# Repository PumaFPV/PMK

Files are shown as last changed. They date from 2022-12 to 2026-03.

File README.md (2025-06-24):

# Puma Mechanical Keyboard
PMK - a full wireless HID ecosystem for split keyboards and other fun devices

The goal is to make a suit of wireless devices such as "smart keyboard" (combined mouse and keyboard), gamepad, LEDs, knobs, display, etc  
The first step is to make a wireless split keyboard, and then we will see later...

Currently, you can connect up to 8 (software limited) devices per dongle, each of them having up to 8 (software limited) layers. Layers only affect keyboards and LED.

## Dongle
The dongle is "master" ESP32S2/S3, appears as HID (keyboard, mouse and joystick) and as Mass Storage device Class with config files inside.
Maybe also store password manager later...

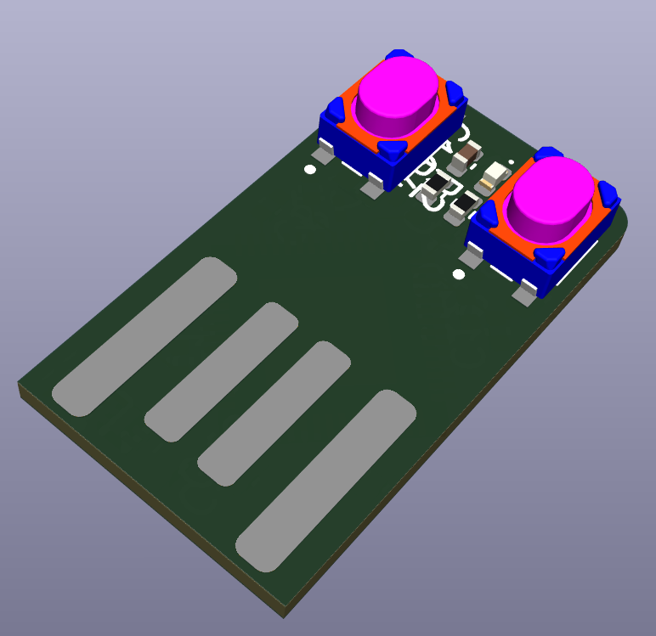
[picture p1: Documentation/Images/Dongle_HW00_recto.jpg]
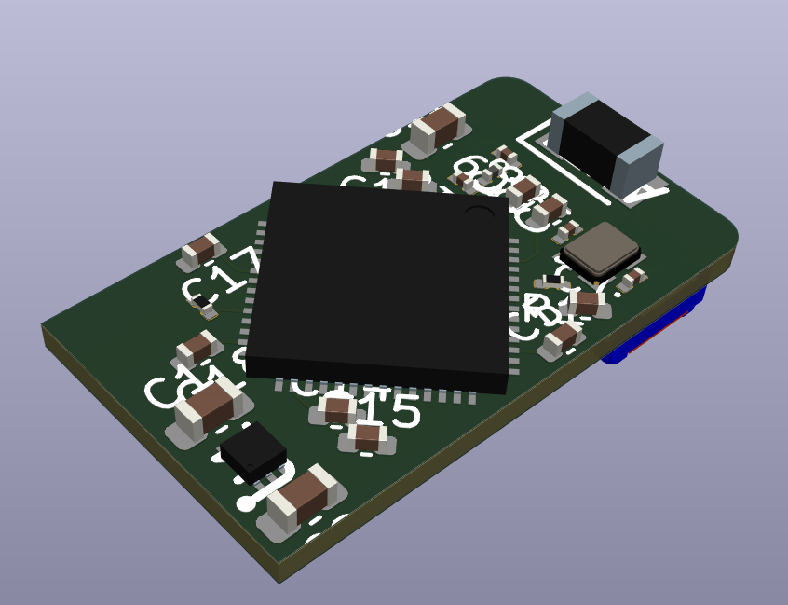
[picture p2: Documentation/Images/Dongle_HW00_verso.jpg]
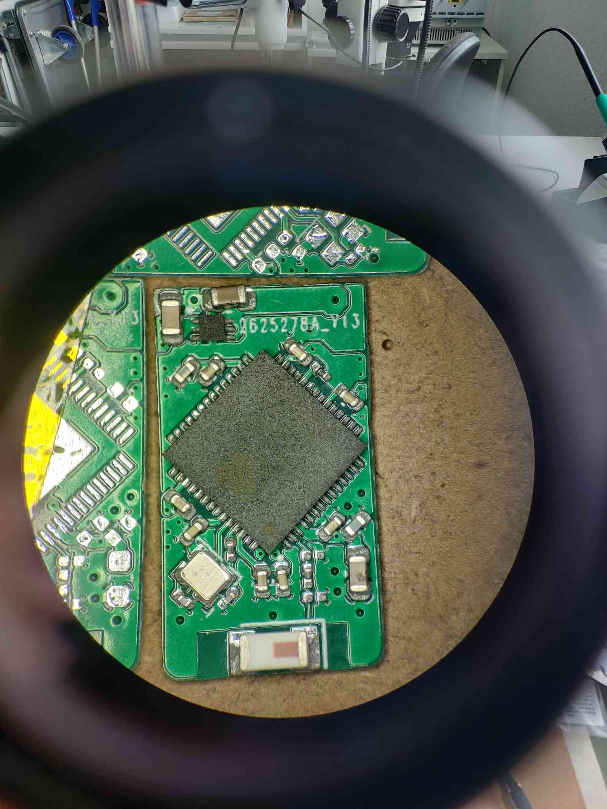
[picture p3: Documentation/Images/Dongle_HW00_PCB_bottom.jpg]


As the dongle is the master of PMK, it hosts the config files for each devices. Here is the expected file organisation:

		|--deviceName1  
		|  |- deviceName1.json  
		|  |--keyboard  
		|  |  |- kb-l1.json  
		|  |  |- kb-l2.json  
		|  |--led  
		|  |  |- led-l1.json  
		|  |  |- led-l2.json  
		|--deviceName2  
		|  |- deviceName2.json  
		|  |--keyboard  
		|  |  |- kb-l1.json  
		|  |  |- kb-l2.json  

Exemple file structure can be found [here](https://github.com/PumaFPV/PMK/tree/main/Software/PMK_dongle/data/leftKB) 

For more details about devices configurations / capabilities check the [Protocol](https://github.com/PumaFPV/PMK?tab=readme-ov-file#protocols) chapter.

### Keyboard config file - HID codes
Check out the [PMK HID keyboard keycodes.md](https://github.com/PumaFPV/PMK/blob/main/PMK%20HID%20keyboard%20keycodes.md) for more information on which code corresponds to which key.

## Devices
Can run on any espressif chip that can run ESP-NOW. (I will later add support for nRF52 chips for lower power consumption, but it will be incompatible with ESP32 hardware)
The plan is to run the simplest firmware on all devices and being able to configure them via their corresponding .json files on the master dongle. 
Each device should be configurable via UART (set device ID, set dongle MAC address, and read device MAC address). 
See sample [device code](https://github.com/PumaFPV/PMK/tree/main/Software/PMK_device) for example. (Needs an update)

### Keyboard
For example a keyboard would send pressed keys number "0x04, 0xA1", which the dongle then reads in the .json as coordinates for returning desired key "a,b", if special key is pressed (volume up, brighntess control...) then do the appropriate consummer control action.
Keys are read with 74HC165 shift registers so theoratically you could have A LOT of keys per keyboard. Current limitation is the max value of keyID which is 255, so there could be a maximum of 255 keys per keyboard (+8 layers...).
For more information about the hardawre, check the [hardware](https://github.com/PumaFPV/PMK/tree/main?tab=readme-ov-file#hardware) section.
A casing is being designed, it is 3D printable. As foam grid is put inside for better sound (I think it is better?). 
It support module on the thumb side ([Circle trackpad](https://www.cirque.com/glidepoint-circle-trackpads) and [3D mouse](https://hackaday.io/project/187172-os3m-mouse)). Both modules have been tested and work. See [Space mouse](https://github.com/PumaFPV/PMK/tree/main?tab=readme-ov-file#space-mouse) section for more info.

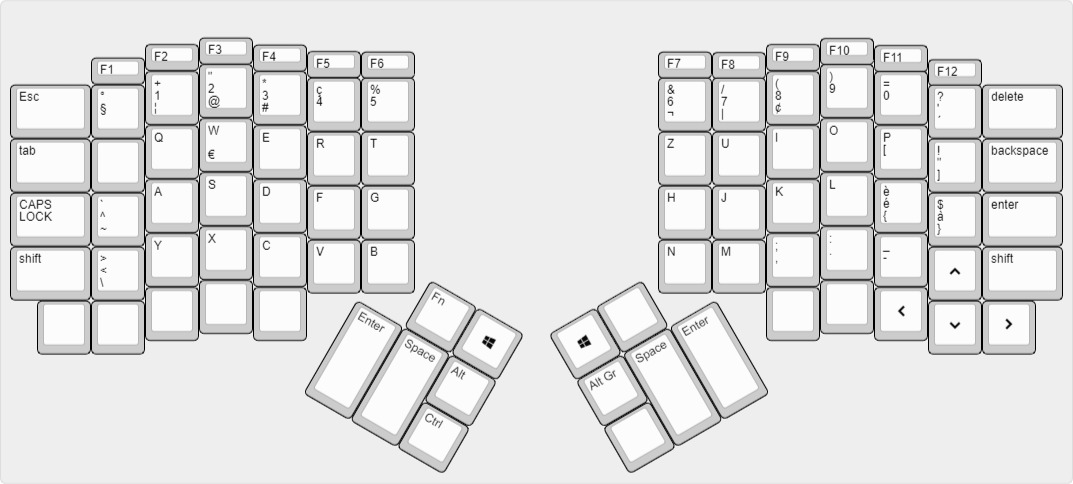
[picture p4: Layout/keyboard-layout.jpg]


### Mouse
Mouse can send x,y movement, wheel, pan scrolling and mouse buttons (left, middle, right, forward, backward). Each button is encoded as a bit in the "key" byte of the packet.
No configuration needed on the dongle appart from the DPI setting.
I plan on retro fitting a wired Logitech G300 with PMK so that it frees up a USB port + becomes wireless. It will be a great first POC. I also have a M330 laying around. It might also end up as a PMK mouse.

### Gamepad
Gamepad can send 2 analog joysticks, 2 analog triggers, dpad buttons, and 32 additionnal buttons. No additionnal configuration needed on the dongle.
I current upgraded an old thrustmaster sim set (FCS & WCS) from 1992 with PMK. They used to have an ADB port, but now both are fully wireless and appear as one gamepad on the computer. The update is a bit crude as it was first though as a POC for trying out the gamepad feature. But since it works fine, I kept it this way.

### LED
(For release 1.2.0)
Hopefully processing key press and led function on dongle and send data to device is fast enough, otherwise I will have to run led function on keyboard. (TODO)
Buildin keyboard functions: all kb, breath, swipe wave (single color or rainbow), key wave, single key... (TODO / Partially implemented...)
Uses the WS2812 kind of LED IC.

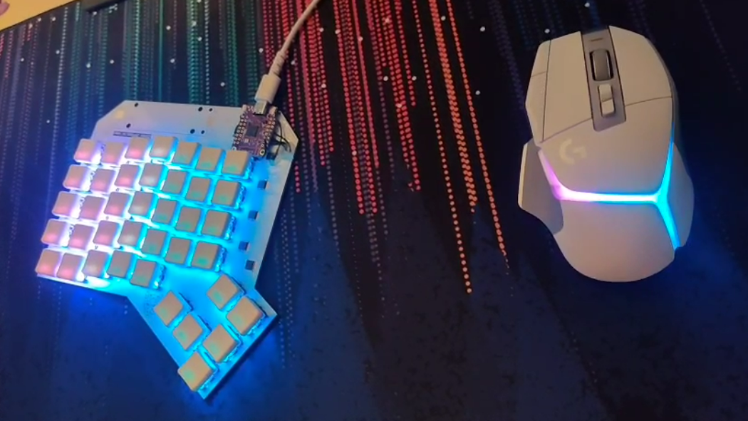
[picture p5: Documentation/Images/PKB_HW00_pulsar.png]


### Knob
Knobs are in absolute position going from 0 to 255. Could be used for Deej (now only used for deej).

For encoder knobs, this is handled on the device, so it can enumerate as a keyboard pressing one key for clockwise and another for counterclockwise rotation. But it could also be treated as an absolute position depending on the device software.

### Space mouse
The software is mostly inspired from [Magellan](https://github.com/jfedor2/magellan-spacemouse/tree/master) and from reports analysed from a 3DConnexion Space mouse with [hid-tool](https://gitlab.freedesktop.org/libevdev/hid-tools). 
The current electronics and plastics hardware are from [OS3M mouse](https://hackaday.io/project/187172-os3m-mouse) and it works well. The software still needs some adjustements for calibration.
Note: If standard VIK connector is needed, PCB has to be flipped. No special hardware modifications are needed.

## Protocols

### ESP-NOW - Device to Dongle
This is the packet sent via ESP-NOW. 
Packet structure is: 
| Byte | 1 | 2 | 3-16 |
| ---- | - | - | - |
| Description | DeviceID | PacketID | Payload |

The goal of this packet strucure is that the dongle knows who is sending data and what kind of data to expect from the payload.
The deviceID is mostly used for keyboards and mouse to use the corresponding config files.

the payload's goal is to send data as simple as possible, e.g. keyboard sends key IDs pressed (max 8 at a time) and then the dongle processes the key ID depending on the json configuration

| Packet ID | Packet type | Packet information | Number of bytes | Example packet | Example description |
| --- | --- | --- | --- | --- | --- |
| 0x00 | Telemetry | Send battery voltage, temperature, mac address, errors... | 15 | dID 00 battery temperature address[6] err err err err err |  |
| 0x01 | Keyboard | 1 byte = 1 key ID | 8 | dID 01 A2 34 DB 32 21 4F 00 00 | 6 keys are pressed |
| 0x02 | Mouse | move x, move y, wheel, pan, mouse clicks | 7 | dID 02 xx yy ww pp kk |move x relative, move y relative, move w relative, move p relative, kk key press|
| 0x03 | Gamepad | 2 joysticks, 2 analog triggers, 9 directions d pad, 32 buttons | 12 | dID 03 xx yy zz rz rx ry hh bb bb bb bb bb |  |
| 0x04 | LED | Choose pre defined function, and R, G and B | 8 | dID 04 func ledNumberStart ledNumberEnd Red Green Blue |  |
| 0x05 | Knob / Rotary encoder / potentiometer | each byte is a pot value, max 8 pot per MCU | 10 | dID 05 FF 00 FF 00 FF 00 FF 00 | 4 pots are at max, 4 are at min |
| 0x06 | Actuator | Choose command type (torque, speed, position) | 5 | dID 06 01 |  |
| 0x07 | Display | send image to display using wifi for faster refresh rate? or store on local mem | 6 | dID 07 imgNumber x y brightness | Display img number n at coordinates x,y and brightness b. Might change later |
| 0x08 | Serial | send up to 8 bytes of data | 10 | dID 08 aa bb cc dd ee ff gg hh | Sending 8 bytes of data |
| 0x09 | SpaceMouse | send 3 bytes for translation (x, y, z) and 3 bytes for rotation (x, y, z), signed intergers | 6 | dID 7F 00 00 FF 00 00 | Positive translation on x and negative rotation on x |

### Serial config - Dongle to PC
The dongle supports a few serial commands, they only consist of a string, no CR/LF should be send or the command won't be recongnised. (The received command is hashed into a number then switched cased to the correct function)
Here is the list of supported commands:
  - h / help : display available commands
  - info : display all info
  - macaddress / getmacaddress : display dongle MAC address
  - version : display build date and version
  - power : display RF Tx power
  - cpu : display cpu info
  - format : format file system
  - restart / reboot : restart the dongle
  - deej : toggle on / off deej
  - config / load: Reload configuration files
  - l0 / l1 / l2... : Force the current layer to... If one keybind moves to new layer it will be ignored use l-1 command to reset force layer
  - l-1 : disable forced layer
  - debug1 / debug2... : Toggle debug output. Different kind of debug available

### Serial config - Device to PC
Before being able to communicate with the dongle, the device has to know the dongle MAC address, and must own a deviceID. You will also need to know the device MAC address to give it to the dongle.
Here is the list of supported commands:
- h / help : returns available commands
- info : display all info
- macaddress / getmacaddress : returns device MAC address
- setdonglemacaddress : update dongle MAC address, be sure to send values in HEX mode
- getdonglemacaddress : returns the current dongle MAC address
- setdeviceid : update deviceID to new value
- getdeviceid : returns currently set devi
- version : returns build date and version
- power : returns RF Tx power
- cpu : returns CPU info
- setcpufreq : set new CPU frequency
- restart : restart the dongle
- scan : Scan for side module presence
- debug1 / debug2... : Toggle debug output. Different kind of debug available

## Hardware
### The dongle
Dongle is still HW00 (first rev), it needs 3 small patches to work properly. A [HW01](https://github.com/PumaFPV/PMK/tree/main/Hardware/PMK_Dongle/PMK_Dongle_HW01) is designed but hasn't been ordered yet.
The ESP32S2 has some limitations, so a ESP32S3 dongle is being made too [here](https://github.com/PumaFPV/PMK/tree/main/Hardware/PMK_Dongle/PMK_Dongle_S3_HW00).

Even a nRF52 dongle might be made... Who knows[?](https://github.com/PumaFPV/PMK/tree/main/Hardware/PMK_Dongle/PMK_Dongle_C_nRF_HW00)

### The keyboard
As of today the keyboard is at the HW02 stage, and uses the sofle layout (which I do like). It uses 29 hot swappable Kailh Choc switches + one rotary encoder. The MCU is a [PSoM module](https://github.com/PumaFPV/PSoM) (homemade SoM) with an ESP32S2 inside. The SoM allows for quick swap of different MCU to try out different feature. Today the ESP32S2 is used for the ease of software developpement. Its power consumption is bad I am aware. But at least software works.
Here is the changelog.

| HW rev | change list |
| --- | --- |
| HW00 | Based on moonlander layout, integrated ESP32, used as a proof of concept, didn't like the layout in the end |
| HW01 | Based on Sofle, PSoM connector (swappable uC for futur proofing), added rotary encoder, way better layout in my opinion. Added side connector option for trackpad or space mouse |
| HW02 | Still soffle, added support for kailh choc V2 (failed), moved the rotary encoder up, added debouncing for rotary encoder, fixed the side module connector, moved test point to accessible location, updated PSoM pinout for better compatibility |
| HW03 (WIP)  | Still soffle, fixed the silkscreen, Added slot for dongle, fixed V2 footprint, magnetic pogo module? |

More info on [Notion](https://swamp-zydeco-907.notion.site/PumaKeyBoard-b41d42fec8c74b02bc73637fae3648d7)

### Edit the PCBs
If you want to make your own keyboard, or visualize current dongle, keyboard or other devices you will need KiCAD 8 and Component_lib which is my own components library. It can be found in its [own repo](https://github.com/PumaFPV/Component_lib), information on own to install it can be found there.

# Building 
This whole project is built using PlatformIO on VS Code / VS Codium. (If using VS Codium note that the marketplace for extensions doesn't really work, you will need to download cpp and platformIO .vsix extension files from https://marketplace.visualstudio.com/vscode)

Once this is installed you can clone PMK's repo ````git clone https://github.com/PumaFPV/PMK````
and open whichever code you want to build / modify: ````PMK/Software/PMK_keyboard```` with platformIO "Open project".

Once project is opened and loaded (might take a few minutes for the first time) (it needs internet connection to download library and toolchain) you can compile with ````ctrl + shift + B```` or ````ctrl + shift + U```` to compile and upload, or use the bottom ribbon (make sure to select the correct workspace before compiling and uploading).

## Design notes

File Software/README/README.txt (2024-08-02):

Add the "pmk_dongle_s2.json" file to "C:\Users\<user>\.platformio\platforms\espressif32\boards"
Add the "pmk_dongle_s2" folder to "C:\Users\<user>\.platformio\packages\framework-arduinoespressif32\variants"

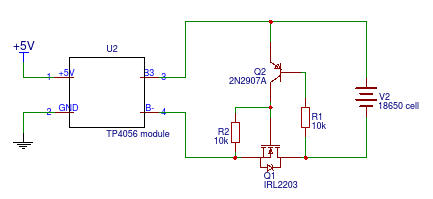
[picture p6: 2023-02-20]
Hardware/PMK_Keyboard/PMK_Keyboard_HW01/Doc/battery_protection_low_rdson_mosfet_simpler_clean.png

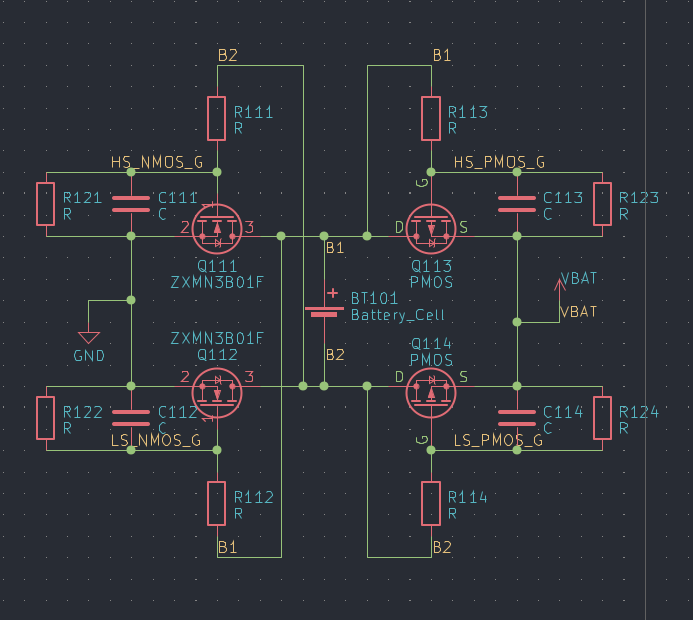
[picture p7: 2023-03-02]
Hardware/PMK_Keyboard/PMK_Keyboard_HW01/Doc/Anti reverse battery.png

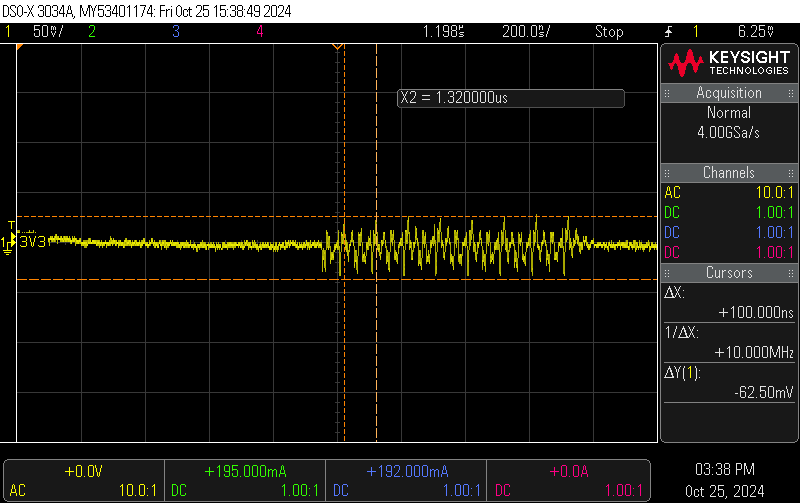
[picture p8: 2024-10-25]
Software/Ticket documentation/Debounce/PU_KEY_AC7.png

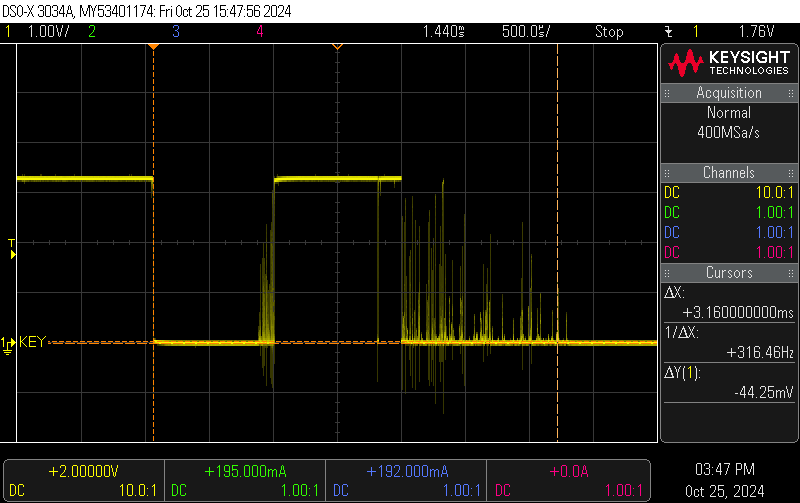
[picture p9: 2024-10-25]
Software/Ticket documentation/Debounce/key_debounce3.png

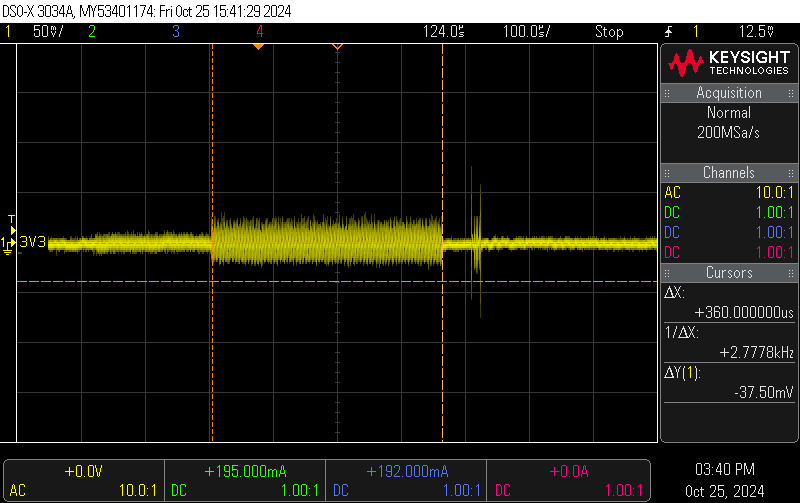
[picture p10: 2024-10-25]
Software/Ticket documentation/Debounce/PU_KEY_AC3.png

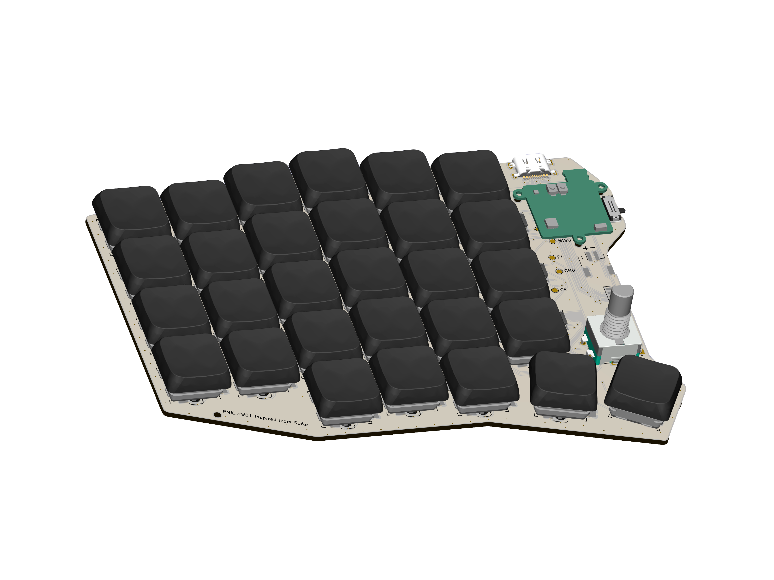
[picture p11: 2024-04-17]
Documentation/Marketing/leftKB_nobg.png

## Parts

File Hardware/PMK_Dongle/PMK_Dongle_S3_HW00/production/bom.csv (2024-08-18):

Designator | Footprint | Quantity | Value | LCSC Part #
ANT1 | ANTC3216X140N | 1 | 2450AT18A100E
C1, C2 | 0603 | 2 | 2u2
C10, C9 | 0201 | 2 | C
C11 | 0603 | 1 | 10u
C12, C15 | 0402 | 2 | 1u
C13, C14, C16, C17, C18, C5, C6, C7, C8 | 0402 | 9 | 100n
C19 | 0402 | 1 | 1p
C3, C4 | 0201 | 2 | 15p
D1 | 0402 | 1 | LED
IC1 | QFN40P700X700X90-57N-D | 1 | ESP32-S2FH4
J1 | USB_PCB | 1 | USB_A
L1 | 0201 | 1 | L
L2 | 0402 | 1 | 2.7n
L3 | 0402 | 1 | 3.9n
R1 | 0201 | 1 | 0
R2 | 0402 | 1 | 2k
R3, R4, R5, R6 | 0201 | 4 | 10k
S1, S2 | B3U-1000P | 2 | SKRPABE010
U1 | SON40P120X120X60-7N-D | 1 | MIC5528-3.3YMT-T5
Y1 | Crystal_SMD_2016-4Pin_2.0x1.6mm | 1 | Crystal_GND24_Small

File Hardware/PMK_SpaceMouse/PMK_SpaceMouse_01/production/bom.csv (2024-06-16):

Designator | Footprint | Quantity | Value | LCSC Part #
C1, C2, C3, C4, C6, C7 | 0402 | 6 | 1n
C10, C8 | 0402 | 2 | 10u
C11, C9 | 0402 | 2 | 1u
C12 | 0402 | 1 | 10n
J1 | GCT_FFC2B28-12-G | 1 | FFC2B28-12-G
L1, L2, L3, L4, L5, L6 | COIL_PCB | 6 | PCB_COIL
R1, R2 | 0402 | 2 | 5k1
R3, R4 | 0402 | 2 | 10k
TP1, TP10, TP11, TP12, TP2, TP3, TP4, TP5, TP6, TP7, TP8, TP9 | TestPoint_Pad_D1.5mm | 12 | GND
U1 | WQFN-16-1EP_4x4mm_P0.5mm_EP2.6x2.6mm | 1 | LDC1614
U2 | WSON-12-1EP_4x4mm_P0.5mm_EP2.6x3mm | 1 | LDC1612
X1 | Oscillator_SMD_Abracon_ASV-4Pin_7.0x5.1mm | 1 | ASV-40.000MHz

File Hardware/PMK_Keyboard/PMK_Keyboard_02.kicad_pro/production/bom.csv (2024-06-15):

Designator | Footprint | Quantity | Value | LCSC Part #
C401, C402 | 0402 | 2 | 10n
C403 | 0402 | 1 | 100n
D501, D502, D503, D504, D505, D506, D507, D508, D509, D510, D511, D512, D513, D514, D515, D516, D517, D518, D519, D520, D521, D522, D523, D524, D525, D526, D527, D528, D529, D530 | YF923_2020_WS2812_LED_DUALSIDE | 30 | YF923_2020_WS2812_LED
J201, J202 | PSoM_ESP32S2_00 | 2 | PSoM_ESP32S2_Carrier_Board
J301 | USB4510031A | 1 | USB4510-03-1-A
J302 | PinHeader_1x02_P2.54mm_Vertical | 1 | Conn_01x02
J303 | JST_PH_S2B-PH-SM4-TB_1x02-1MP_P2.00mm_Horizontal_DUALSIDE | 1 | S2B-PH-SM4-TB
J304, J305 | GCT_FFC2B28-12-G | 2 | FFC2B28-12-G
R201, R202 | 0402 | 2 | R
R303, R304 | 0402 | 2 | 5.1k
R305, R306 | 0402 | 2 | 0
R401, R402, R403, R404 | 0201 | 4 | 10k
RN401, RN402, RN403, RN404 | EXB2HV_1 | 4 | EXB-2HV103JV
SW301 | 450405020524_DUALSIDE | 1 | 450405020524
SW401, SW402, SW403, SW404, SW405, SW406, SW407, SW408, SW409, SW410, SW411, SW412, SW413, SW414, SW415, SW416, SW417, SW418, SW419, SW420, SW421, SW422, SW423, SW424, SW425, SW426, SW427, SW428, SW429 | Kailh_socket_PG1350_reversible_V1V2 | 29 | SW_Push
SW430 | RIC11-22S10D5S-TH | 1 | RIC11-22S10D5S-TH
TH201, TH202 | 0402 | 2 | Thermistor_NTC
TP201 | TestPoint_Pad_D1.5mm | 1 | 3V3
TP202 | TestPoint_Pad_D1.5mm | 1 | PL
TP203 | TestPoint_Pad_D1.5mm | 1 | SR_CE
TP204 | TestPoint_Pad_D1.5mm | 1 | SPI_CLK
TP205 | TestPoint_Pad_D1.5mm | 1 | MISO
TP206 | TestPoint_Pad_D1.5mm | 1 | RX
TP207 | TestPoint_Pad_D1.5mm | 1 | TX
TP208 | TestPoint_Pad_D1.5mm | 1 | GND
U401, U402, U403, U404 | SOP65P640X120-16N | 4 | SN74HC165PWR
U405 | SOP95P280X145-6N | 1 | SN74LVC2G04DBVRG4

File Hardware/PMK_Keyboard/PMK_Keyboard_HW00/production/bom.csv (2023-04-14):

Designator | Footprint | Quantity | Value | LCSC Part #
ANT401 | ANTC3216X140N | 1 | 2450AT18A100E
BT101 | BatteryHolder_Keystone_1042_1x18650_DUALSIDE | 1 | Battery_Cell
C201, C203 | 0603 | 2 | 4u7
C202 | 0603 | 1 | 1u
C301, C302, C303, C304 | 0603 | 4 | 2u2
C401, C402 | 0201 | 2 | 15p
C403, C404, C405, C408, C411, C412, C414, C415, C416 | 0402 | 9 | 100n
C406, C407 | 0201 | 2 | C
C409 | 0603 | 1 | 10u
C410, C413 | 0402 | 2 | 1u
D201, D202, D401 | 0402 | 3 | LED
D601, D602, D603, D604, D605, D606, D607, D608, D609, D610, D611, D612, D613, D614, D615, D616, D617, D618, D619, D620, D621, D622, D623, D624, D625, D626, D627, D628, D629, D630, D631, D632, D633, D634, D635, D636, D637, D638, D639, D640 | YF923_2020_WS2812_LED_DUALSIDE | 40 | YF923_2020_WS2812_LED
J101 | USB4510031A | 1 | USB4510-03-1-A
J401 | PinHeader_1x08_P1.27mm_Vertical | 1 | Conn_01x08_Female
J402 | PinHeader_1x03_P2.54mm_Vertical | 1 | Conn_01x03_Socket
L401 | 0201 | 1 | L
R101, R102 | 0201 | 2 | 5.1k
R201 | 0402 | 1 | 0
R202 | 0402 | 1 | 36k5
R203 | 0402 | 1 | 590
R204 | 0402 | 1 | 1k1
R205, R206 | 0402 | 2 | 1k5
R207 | 0402 | 1 | 100k
R301 | 0201 | 1 | 0k
R401 | 0201 | 1 | 0
R402 | 0402 | 1 | 2k
R403, R404 | 0201 | 2 | 10k
R405, R406, R407, R408 | 0201 | 4 | nu
RN501, RN502, RN503, RN504, RN505 | EXB2HV_1 | 5 | EXB-2HV103JV
S401, S402 | SKRPABE010 | 2 | SKRPABE010
SW501 | SKRPABE010 | 1 | SW_Push
SW502, SW503, SW504, SW505, SW506, SW507, SW508, SW509, SW510, SW511, SW512, SW513, SW514, SW515, SW516, SW517, SW518, SW519, SW520, SW521, SW522, SW523, SW524, SW525, SW526, SW527, SW528, SW529, SW530, SW531, SW532, SW533, SW534, SW535, SW536, SW537, SW538, SW539, SW540 | Kailh_socket_PG1350_reversible | 39 | SW_Push
TP201 | TestPoint_Pad_D1.0mm | 1 | TestPoint
U201 | QFN50P300X300X100-17N-D | 1 | BQ24075RGTR
U301, U302 | SON40P120X120X60-7N-D | 2 | MIC5528-3.3YMT-T5
U401 | QFN40P700X700X90-57N-D | 1 | ESP32-S2FH4
U501, U502, U503, U504, U505 | SOP65P640X120-16N | 5 | SN74HC165PWR
Y601 | Crystal_SMD_2016-4Pin_2.0x1.6mm | 1 | Crystal_GND24_Small

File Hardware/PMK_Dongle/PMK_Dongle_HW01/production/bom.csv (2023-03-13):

Designator | Footprint | Quantity | Value | LCSC Part #
ANT1 | ANTC3216X140N | 1 | 2450AT18A100E
C1 | 0603 | 1 | 10u
C10 | 0201 | 1 | C
C11 | 0603 | 1 | 10u
C12 | 0402 | 1 | 1u
C13 | 0402 | 1 | 100n
C14 | 0402 | 1 | 100n
C15 | 0402 | 1 | 1u
C16 | 0402 | 1 | 100n
C17 | 0402 | 1 | 100n
C18 | 0402 | 1 | 100n
C2 | 0603 | 1 | 10u
C3 | 0201 | 1 | 15p
C4 | 0201 | 1 | 15p
C5 | 0402 | 1 | 100n
C6 | 0402 | 1 | 100n
C7 | 0402 | 1 | 100n
C8 | 0402 | 1 | 100n
C9 | 0201 | 1 | C
D1 | 0402 | 1 | LED
IC1 | QFN40P700X700X90-57N-D | 1 | ESP32-S2FH4
J1 | USB_PCB | 1 | USB_A
L1 | 0201 | 1 | L
R1 | 0201 | 1 | 0
R2 | 0402 | 1 | 2k
R3 | 0201 | 1 | 10k
R4 | 0402 | 1 | 10k
S1, S2 | SKRPABE010 | 2 | SKRPABE010
U1 | SON40P120X120X60-7N-D | 1 | MIC5528-3.3YMT-T5
Y1 | Crystal_SMD_2016-4Pin_2.0x1.6mm | 1 | Crystal_GND24_Small

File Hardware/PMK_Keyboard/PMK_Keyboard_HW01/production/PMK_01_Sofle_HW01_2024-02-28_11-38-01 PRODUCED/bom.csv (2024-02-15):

Designator | Footprint | Quantity | Value | LCSC Part #
D501, D502, D503, D504, D505, D506, D507, D508, D509, D510, D511, D512, D513, D514, D515, D516, D517, D518, D519, D520, D521, D522, D523, D524, D525, D526, D527, D528, D529 | YF923_2020_WS2812_LED_DUALSIDE | 29 | YF923_2020_WS2812_LED
J201, J202 | PSoM_ESP32S2_00 | 2 | PSoM_ESP32S2_Carrier_Board
J303 | USB4510031A | 1 | USB4510-03-1-A
J304 | SMD_CONN_01x5_1.5mm | 1 | Conn_01x05_Pin
J305 | 5051101292 | 1 | 505110-1292
J306 | JST_PH_S2B-PH-SM4-TB_1x02-1MP_P2.00mm_Horizontal_DUALSIDE | 1 | S2B-PH-SM4-TB
R201, R202 | 0402 | 2 | R
R303, R304 | 0402 | 2 | 5.1k
R305, R306 | 0402 | 2 | 0
RN401, RN402, RN403, RN404 | EXB2HV_1 | 4 | EXB-2HV103JV
SW301 | 450405020524_DUALSIDE | 1 | 450405020524
SW401, SW402, SW403, SW404, SW405, SW406, SW407, SW408, SW409, SW410, SW411, SW412, SW413, SW414, SW415, SW416, SW417, SW418, SW419, SW420, SW421, SW422, SW423, SW424, SW425, SW426, SW427, SW428, SW429 | Kailh_socket_PG1350_reversible | 29 | SW_Push
SW430 | RIC11-22S10D5S-TH | 1 | RIC11-22S10D5S-TH
TH201, TH202 | 0402 | 2 | Thermistor_NTC
TP201, TP202, TP203, TP204, TP205, TP206 | TestPoint_Pad_D1.5mm | 6 | TestPoint
U401, U402, U403, U404 | SOP65P640X120-16N | 4 | SN74HC165PWR

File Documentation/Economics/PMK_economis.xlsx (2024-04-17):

Item | Quantity | total price
PMK_dongle_00 PCB | 5 | 2.39
PMK_KB_00 PCB | 5 | 15.9
PMK_KB_01 PCB | 5 | 9.7
PMK_Dongle_00 stencil | 1 | 6.62
PMK_KB_00_stencil | 1 | 6.62
PSoM | 2 | 20
keycap |  | 22.17
switch |  | 83.97
RE | 4
components |  | 175
R&D |  | 19.1
 |  | 361.47

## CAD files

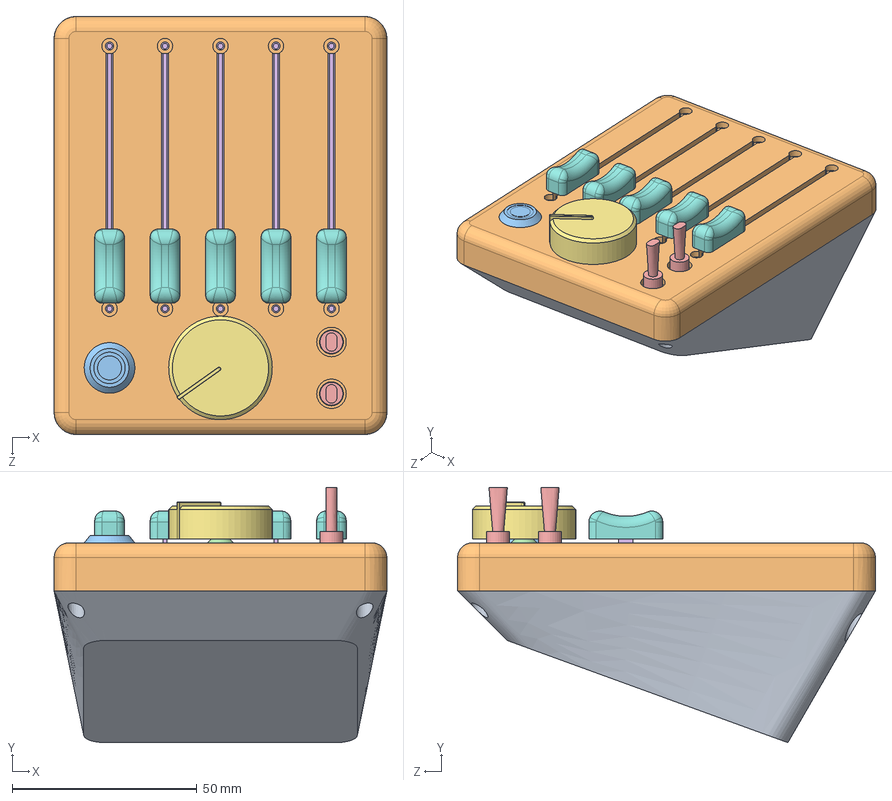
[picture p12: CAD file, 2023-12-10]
Mecha/Deej/Deej.SLDASM
90.0 x 69.0 x 113.0 mm
Bottom
Top_cover
Mute
Potar
Switch x 2
Slider x 5
Knob
Slider top x 5

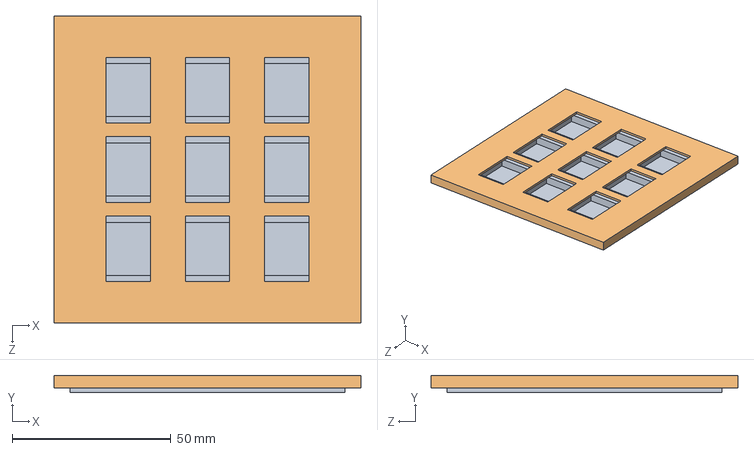
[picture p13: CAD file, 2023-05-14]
Mecha/Keyboard/KeyCap holder/keycap holder.SLDASM
96.7 x 5.50 x 96.7 mm
keycap matrice
holder^keycap holder

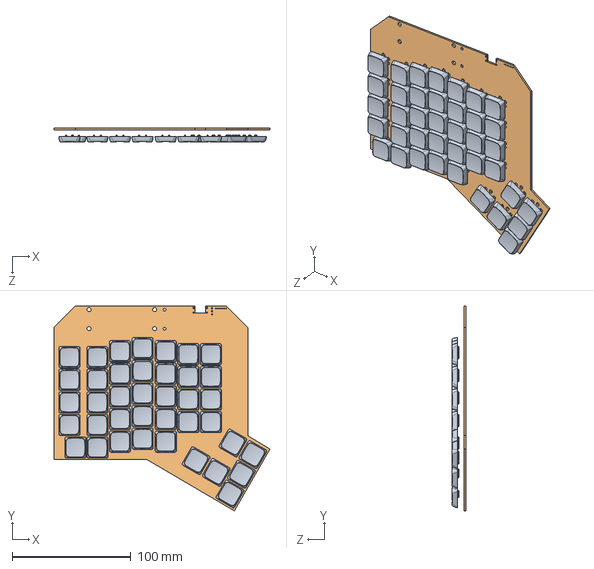
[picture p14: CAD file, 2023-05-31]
Mecha/Keyboard/PMK_00/PMK_Keyboard.SLDASM
181.6 x 172.3 x 11.9 mm
SOLID-0.step x 39
PCB.step

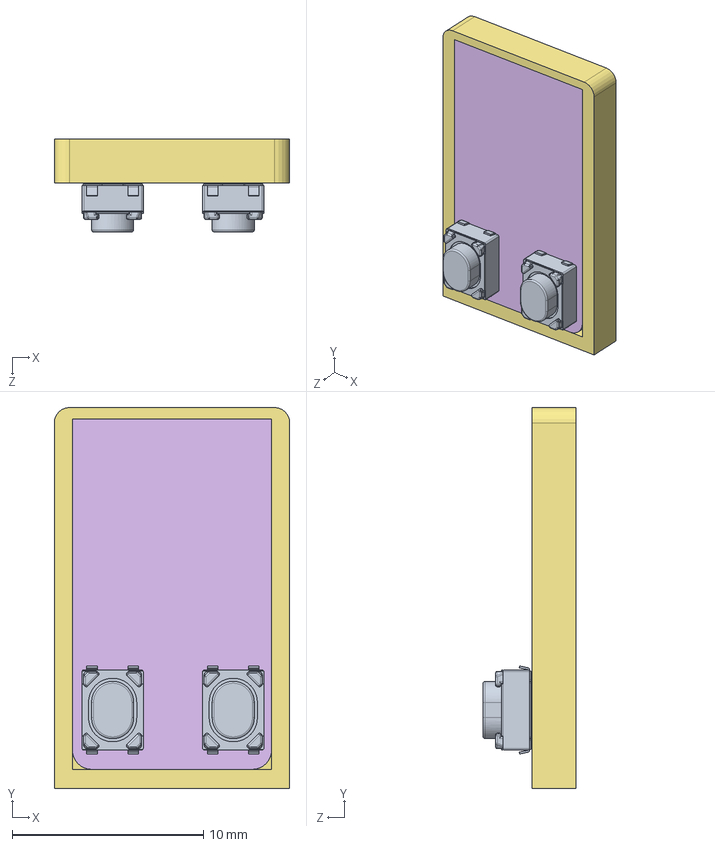
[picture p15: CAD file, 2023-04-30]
Mecha/Dongle/Dongle assembly.SLDASM
12.3 x 19.9 x 4.85 mm
SOLID.step x 2
COMPOUND.step
COMPOUND-0.step
COMPOUND-1.step
COMPOUND-2.step
PCB.step
Casing

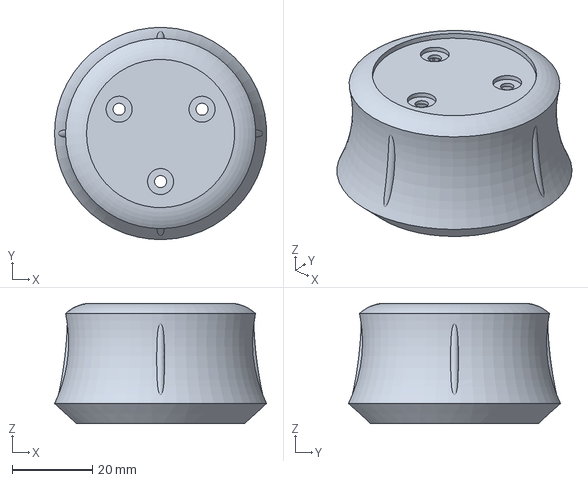
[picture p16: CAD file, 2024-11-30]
Mecha/3D mouse/3D mouse knob.FCStd
52.9 x 53.0 x 30.0 mm

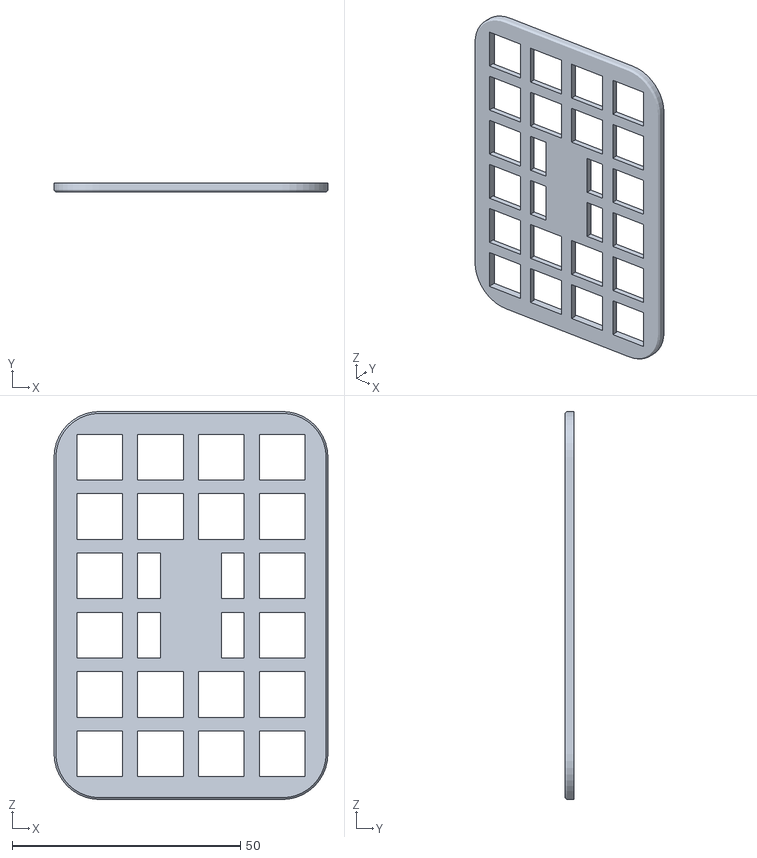
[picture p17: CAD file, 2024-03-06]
Mecha/Dongle/dongle stencil.STL
60.0 x 2.00 x 85.0

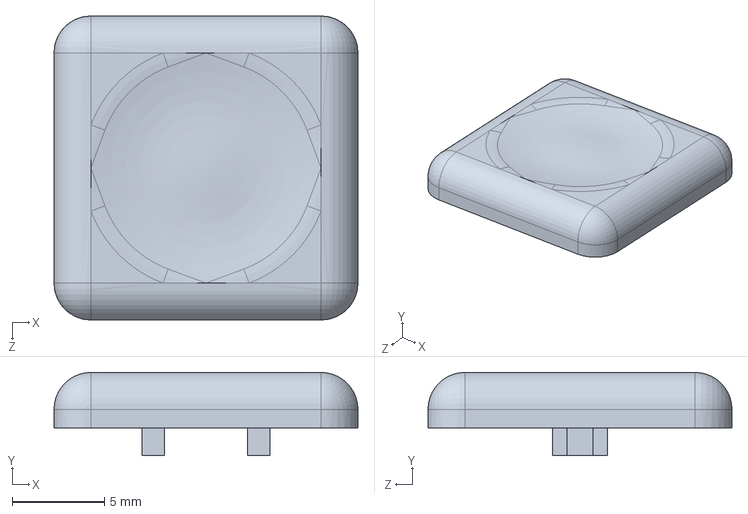
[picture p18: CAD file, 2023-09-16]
Mecha/Keyboard/Keycap/Keycap.SLDPRT
16.5 x 4.50 x 16.5 mm

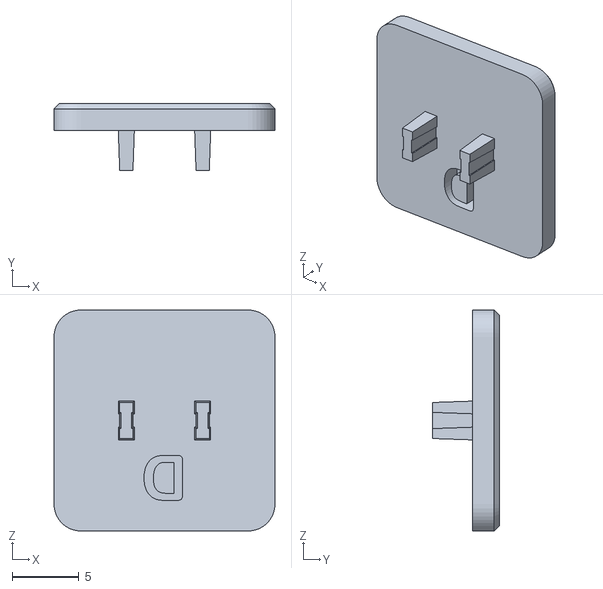
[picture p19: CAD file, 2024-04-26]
Mecha/Keyboard/PMK_01/export/keycap/d.STL
16.5 x 5.00 x 16.5

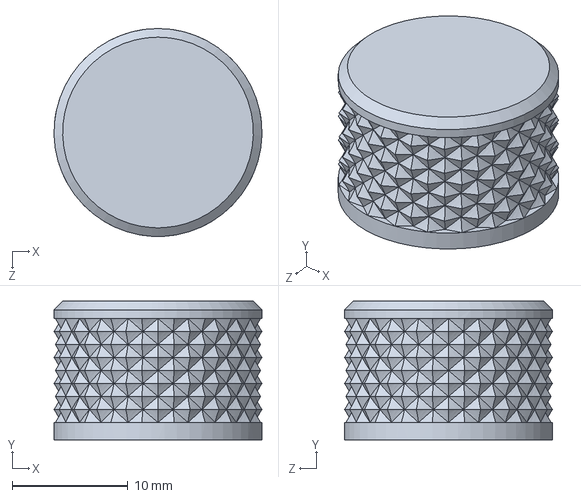
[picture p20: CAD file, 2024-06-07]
Mecha/Keyboard/PMK_01/RotaryKnob.SLDPRT
18.0 x 12.0 x 18.0 mm

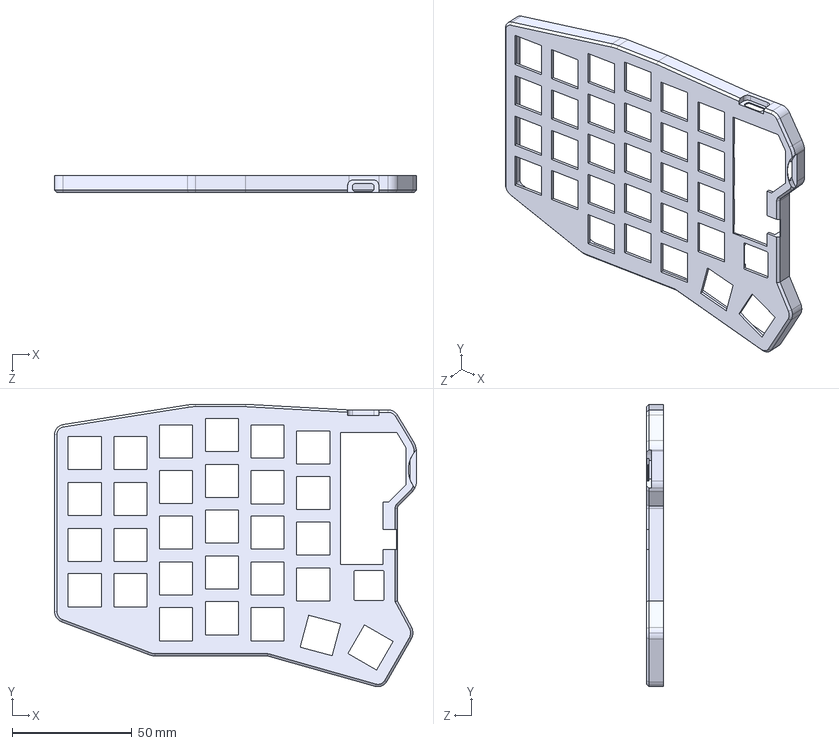
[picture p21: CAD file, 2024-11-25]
Mecha/Keyboard/PMK_02/export/Plate.STEP
150.9 x 117.8 x 7.20 mm

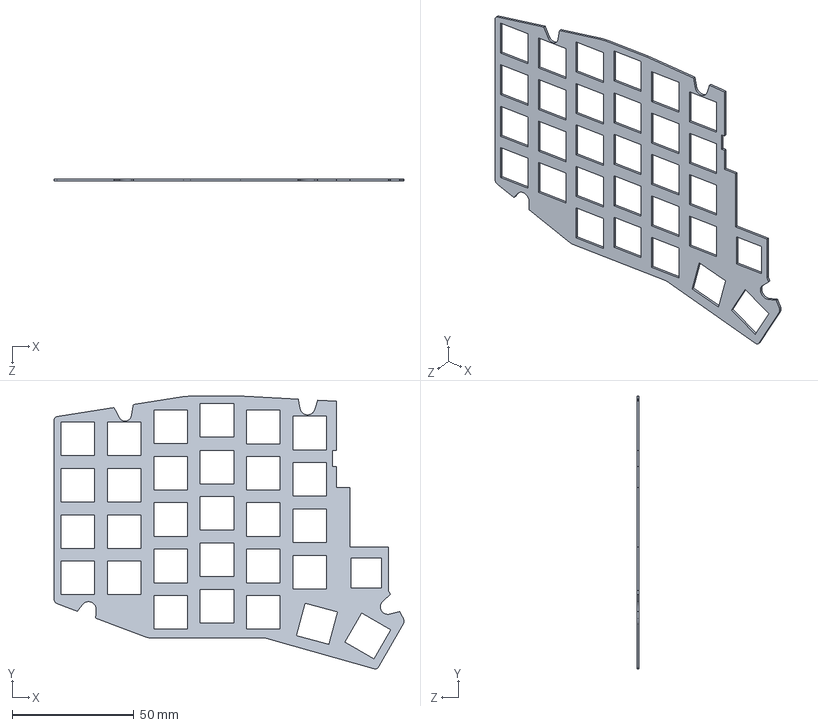
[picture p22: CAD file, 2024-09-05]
Mecha/Keyboard/PMK_02/Foam.SLDPRT
143.8 x 112.2 x 0.95 mm

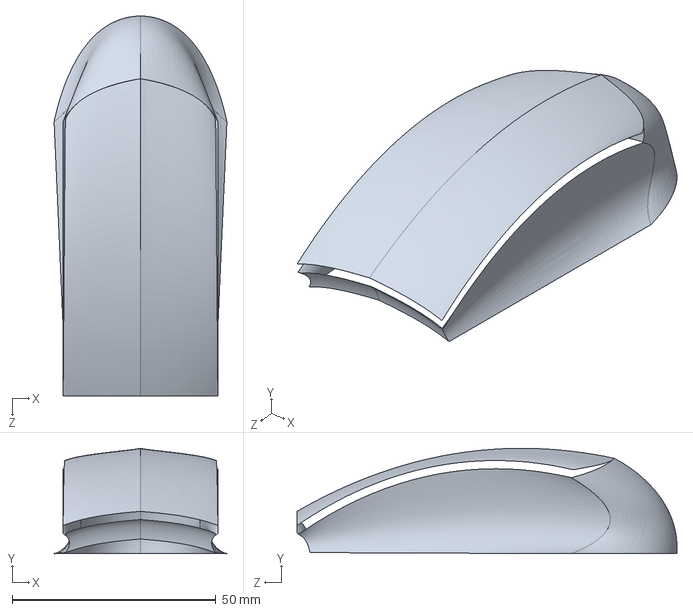
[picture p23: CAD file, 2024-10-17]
Mecha/Mouse/Shell.SLDPRT
42.4 x 25.8 x 93.2 mm

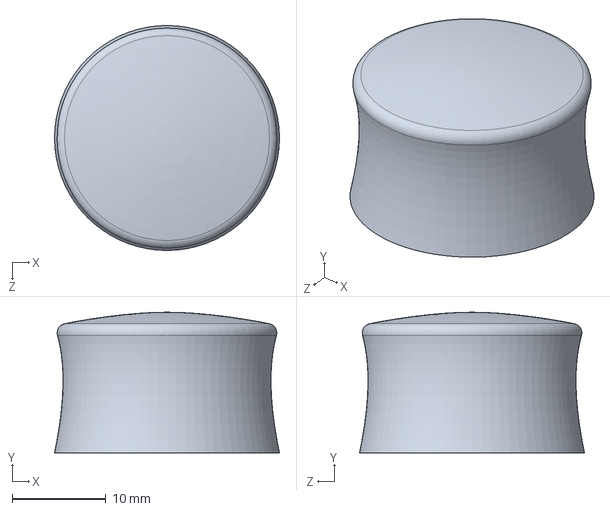
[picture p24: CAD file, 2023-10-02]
Mecha/3D mouse/top.SLDPRT
24.0 x 15.0 x 24.0 mm

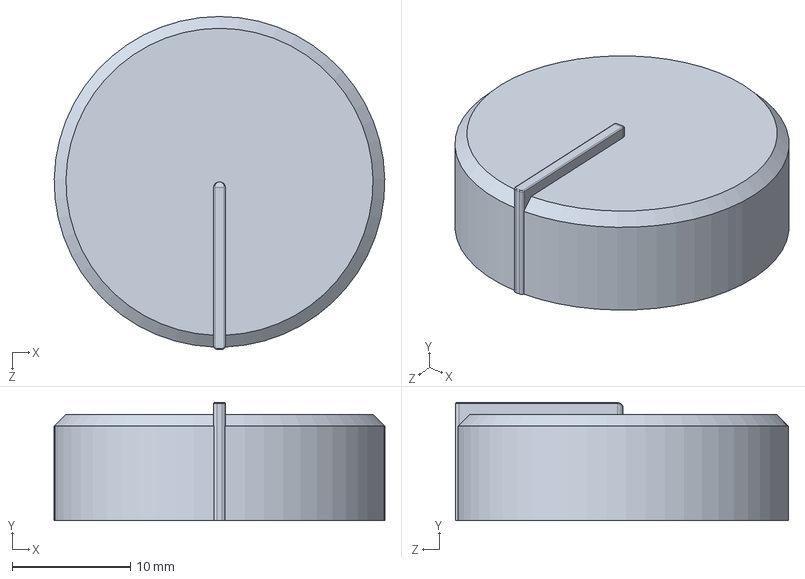
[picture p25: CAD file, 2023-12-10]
Mecha/Deej/Knob.SLDPRT
28.0 x 10.0 x 28.2 mm

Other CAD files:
Mecha/3D mouse/export/3D mouse knob-BodyPolarPattern001.stl
Mecha/Dongle/PMK_Dongle_00.step
Mecha/Keyboard/KeyCap holder/holder^keycap holder.STL
Mecha/Keyboard/Keycap/MBK_Keycap_-_1.5u.SLDPRT
Mecha/Deej/18650.SLDPRT
Mecha/Deej/Bottom.SLDPRT
Mecha/Deej/Export/Bottom.STL
Mecha/Deej/Export/Knob.STL
Mecha/Deej/Export/Slider top.STL
Mecha/Deej/Export/Top_cover.STL
Mecha/Deej/Mute.SLDPRT
Mecha/Deej/Potar.SLDPRT
Mecha/Deej/Slider top.SLDPRT
Mecha/Deej/Slider.SLDPRT
Mecha/Deej/Switch.SLDPRT
Mecha/Deej/Top.SLDPRT
Mecha/Deej/Top_cover.SLDPRT
Mecha/Dongle/Casing.SLDPRT
Mecha/Dongle/Casing.STL
Mecha/Dongle/Casing2.2mm.STL
Mecha/Dongle/PMK_Dongle.step
Mecha/Keyboard/KeyCap holder/keycap matrice.SLDPRT
Mecha/Keyboard/KeyCap holder/keycap matrice.STL
Mecha/Keyboard/Keycap/Keycap.STL
Mecha/Keyboard/Keycap/MBK_Keycap_-_2u.SLDPRT
Mecha/Keyboard/PMK_00/PMK_Keyboard.DXF
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

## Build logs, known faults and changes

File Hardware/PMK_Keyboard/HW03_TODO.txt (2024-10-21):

Schematic:
	Move RE_B to another pim than 15 (buildin_led)
	Update battery connector to molex picoBlade 3 pins
	VIK standard connector

Routing:
	Fix silkscreen HW02 -> HW03
	Add center mounting hole
	Change battery connector
	Update kailh v2 footprint

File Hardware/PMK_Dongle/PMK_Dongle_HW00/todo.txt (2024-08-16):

move LED to gpio1 because gpio46 is input only and strapping
fix button footprint
add gpio45 a pd for strapping

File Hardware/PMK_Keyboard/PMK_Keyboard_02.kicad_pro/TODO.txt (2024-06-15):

Schematic:
	
Routing:
	Move SR away from switch (aluminium plate)

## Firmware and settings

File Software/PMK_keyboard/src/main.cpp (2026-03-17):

#include <Arduino.h>

#include "SPI.h"
#include "Wire.h"
#include "WiFi.h"
#include "esp_now.h"
#include "FastLED.h"
#include "EEPROM.h"
#include "CirquePinnacle.h"
#include "spaceMouseHandle.h"
#include "pmk.h"
#include "SimpleCLI.h"

#include "variables.h"

#define FIRMWARE_REV "keyboard-dev-1.1.0dev"

//#include "uartHandle.h"
#include "commandHandle.h"
#include "i2cHandle.h"
#include "espnowHandle.h"
#include "ledHandle.h"
#include "ioHandle.h"
#include "trackpad.h"


void loopCount();



void setup()
{
  //-----Serial
  Serial.begin(115200);
  //while(!Serial){}

  //-----CLI
  cliSetup();


  //-----CPU
  setCpuFrequencyMhz(80);



  //-----ADC
  //analogSetAttenuation(ADC_ATTEN_DB_12);


  
  //-----GPIO
  pinMode(BUILDIN_LED, OUTPUT);
  digitalWrite(BUILDIN_LED, 1);



  //-----Shift register
  pinMode(SR_PL, OUTPUT);
  // Initialize SPI for SR
  srSpi = new SPIClass(SR_SPI_BUS);
  #ifdef HW01
    srSpi->begin(SR_CLK, SR_MISO, -1, SR_CE);
  #endif
  #ifdef HW02
    srSpi->begin(SR_CLK, SR_MISO, SPI_MOSI, SR_CE);
  #endif
  pinMode(srSpi->pinSS(), OUTPUT);




  //-----I2C
  #ifdef HW02

    Wire.begin(SDA, SCL, i2cClk);

    checkSideModule();
    
  #endif



  //-----Rotary Encoder
  pinMode(RE_A, INPUT_PULLUP);
  //pinMode(RE_B, INPUT_PULLUP);
  attachInterrupt(RE_A, rotaryEncoderISR, RISING);



  //-----Leds
  FastLED.addLeds<WS2812B, LED_DATA_PIN, GRB>(leds, NUM_LEDS);

  currentPalette = RainbowColors_p;
  currentBlending = LINEARBLEND;



  //-----EEPROM
  EEPROM.begin(EEPROM_SIZE);
  deviceID = EEPROM.read(DEVICEID_ADDRESS);
  keyboardPacket.deviceID = deviceID;
  mousePacket.deviceID = deviceID;
  knobPacket.deviceID = deviceID;
  spaceMousePacket.deviceID = deviceID;
  telemetryPacket.deviceID = deviceID;
  
  Serial.printf("Loading dongle MAC address from EEPROM: ");
  for(uint8_t i = 0; i < MAC_ADDRESS_SIZE; i++)
  {
    dongleAddress[i] = EEPROM.read(DONGLE_MACADDRESS_ADDRESS + i);
    delay(50);
    Serial.print(dongleAddress[i], HEX);
  }
  Serial.printf("\r\n");

  ledSleepDelay = EEPROM.read(LED_SLEEP_DELAY_ADDRESS);


  //-----ESP NOW
  WiFi.mode(WIFI_STA);
  delay(10);
  WiFi.setTxPower(WIFI_POWER_19_5dBm);

  if(esp_now_init() != ESP_OK) {
    Serial.println("Error initializing ESP-NOW");
    return;
  }

  // Once ESPNow is successfully Init, we will register for Send CB to
  // get the status of Trasnmitted packet
  esp_now_register_send_cb(OnDataSent);

  // Register dongles
  registerDongle();

  // Register for a callback function that will be called when data is received
  esp_now_register_recv_cb(OnDataRecv);


  if(trackpadIsPresent)
  {
    trackpadSetup();
  }
  
  if(spacemouseIsPresent)
  {
    spacemouseSetup();
  }
  
}



void loop() 
{
  loopCount();



  //------------------------------------------------------
  //------------------------------------------------------ledTask
  //------------------------------------------------------
  if(micros() - ledTask.beginTime >= ledTask.interval)
  {
    ledTask.beginTime = micros();
    ledTask.inBetweenTime = ledTask.beginTime - ledTask.endTime;

      ledLoop();

      // Turn off LEDs after ledSleepDelay
      unsigned long timeSinceLastPacket = millis() - lastSentPacketTime;
      if(timeSinceLastPacket > ledSleepDelay * 60 * SECONDS_TO_MILLIS)
      {
        ledSleepStatus = 1;
      }

    ledTask.endTime = micros();
    ledTask.counter++;
    ledTask.duration = ledTask.endTime - ledTask.beginTime;
  }



  //------------------------------------------------------
  //------------------------------------------------------srTask
  //------------------------------------------------------
  if(micros() - srTask.beginTime >= srTask.interval)
  {
    srTask.beginTime = micros();
    srTask.inBetweenTime = srTask.beginTime - srTask.endTime;

      srLoop();

    srTask.endTime = micros();
    srTask.counter++;
    srTask.duration = srTask.endTime - srTask.beginTime;
  }
  


  //------------------------------------------------------
  //------------------------------------------------------espnowTask
  //------------------------------------------------------
  if(micros() - espnowTask.beginTime >= espnowTask.interval)
  {
    espnowTask.beginTime = micros();
    espnowTask.inBetweenTime = espnowTask.beginTime - espnowTask.endTime;


    /*
    static uint32_t time = 0;
    
    for(uint8_t i = 0; i < 4; i++)
    {
      telemetryPacket.error[i] = (time >> (i*8)) & 0xFF;
      //Serial.printf("%u", telemetryPacket.error[3-i]);
    }
    uint32_t calculatedTime = telemetryPacket.error[0] | telemetryPacket.error[1] << 8 | telemetryPacket.error[2] << 16 | telemetryPacket.error[3] << 24;
    //Serial.printf("time: %u, sent time: %u\r\n", time, calculatedTime);

    esp_now_send(dongleAddress, (uint8_t *) &telemetryPacket, sizeof(telemetryPacket));

    time++;
    */


    espnowTask.endTime = micros();
    espnowTask.counter++;
    espnowTask.duration = espnowTask.endTime - espnowTask.beginTime;

  }



  //------------------------------------------------------
  //------------------------------------------------------Rotary Encoder Task
  //------------------------------------------------------
  if(micros() - reTask.beginTime >= reTask.interval)
  {
    reTask.beginTime = micros();
    reTask.inBetweenTime = reTask.beginTime - reTask.endTime;


      for(int i = 0; i < MAX_NUMBER_OF_DEEJ_KNOBS; i++) 
      {
          if(debug[3])
          {
              Serial.printf("sending knob %i at %i\r\n", i, knobPacket.knob[i]);

          }
      }

      reLoop();

    bool knobContentIsEqual = areArraysEqual(knobPacket.knob, previousKnobPacket.knob, 8);


      if(!knobContentIsEqual)
      {
        esp_now_send(dongleAddress, (uint8_t *) &knobPacket, sizeof(knobPacket));
      }

      for(uint8_t i = 0; i < 8; i++)
      {
        previousKnobPacket.knob[i] = knobPacket.knob[i];
      }

    reTask.endTime = micros();
    reTask.counter++;
    reTask.duration = reTask.endTime - reTask.beginTime;

  }



  //------------------------------------------------------
  //------------------------------------------------------UART Task
  //------------------------------------------------------
  if(micros() - uartTask.beginTime >= uartTask.interval)
  {
    uartTask.beginTime = micros();
    uartTask.inBetweenTime = uartTask.beginTime - uartTask.endTime;

      static char receivedCommand[64];
      static uint8_t i = 0;
      static String command;
      
      uint8_t incominSerial = Serial.read();

      if(incominSerial != 0xFF)
      {
        receivedCommand[i] = incominSerial;
        Serial.printf("%c", incominSerial);
        if(receivedCommand[i] == 0x0D) // 0x0D = \r
        {
          for(uint8_t j = 0; j < i; j++)
          {
            command = command + receivedCommand[j];
          }
          Serial.printf("\r\n");
          cli.parse(command);
          
          i = 0;
          command = "";
        }
        else
        {
          i++;
        }
      }

    uartTask.endTime = micros();
    uartTask.counter++;
    uartTask.duration = uartTask.endTime - uartTask.beginTime;
  }



  //------------------------------------------------------
  //------------------------------------------------------cirque Task
  //------------------------------------------------------
  if(micros() - sideModuleTask.beginTime >= sideModuleTask.interval)
  {
    sideModuleTask.beginTime = micros();
    sideModuleTask.inBetweenTime = sideModuleTask.beginTime - sideModuleTask.endTime;

      if(trackpadIsPresent)
      {
        trackpadLoop();
      }
      
      if(spacemouseIsPresent)
      {
        spacemouseLoop();
      }

    sideModuleTask.endTime = micros();
    sideModuleTask.counter++;
    sideModuleTask.duration = sideModuleTask.endTime - sideModuleTask.beginTime;
  }



  //------------------------------------------------------
  //------------------------------------------------------telemetry Task
  //------------------------------------------------------
  if(micros() - telemetryTask.beginTime >= telemetryTask.interval)
  {
    telemetryTask.beginTime = micros();
    telemetryTask.inBetweenTime = telemetryTask.beginTime - telemetryTask.endTime;


      //uint16_t batteryADC = analogRead(PIN_VBAT);
      uint32_t batteryVolt = analogReadMilliVolts(PIN_VBAT);

      //telemetryPacket.battery = map(batteryADC, 2789, 3550, 0, 100);
      telemetryPacket.battery = map(batteryVolt, 1750, 2100, 0, 100);
      //Serial.printf("%%: %u, mV: %u\r\n", /*batteryADC,*/ telemetryPacket.battery, batteryVolt);

      if(telemetryPacket.battery < LOW_BATTERY_THRESHOLD)
      {
        static bool ledStatus = 0;

        digitalWrite(BUILDIN_LED, ledStatus);
        ledStatus = !ledStatus;
      }

      esp_now_send(dongleAddress, (uint8_t *) &telemetryPacket, sizeof(telemetryPacket));

    telemetryTask.endTime = micros();
    telemetryTask.counter++;
    telemetryTask.duration = telemetryTask.endTime - telemetryTask.beginTime;
  }
}



void loopCount()
{
  //ledTask frequency counter
  if(ledTask.counter == 0)
  {
    ledTask.startCounterTime = micros();
  }
  if(micros() - ledTask.startCounterTime > 1000000)
  {
    ledTask.frequency = ledTask.counter;
    //Serial.println(ledTask.counter);
    ledTask.counter = 0;
  }

  //srTask frequency counter
  if(srTask.counter == 0)
  {
    srTask.startCounterTime = micros();
  }
  if(micros() - srTask.startCounterTime > 1000000)
  {
    srTask.frequency = srTask.counter;
    //Serial.println(srTask.counter);
    srTask.counter = 0;
  }

  //Task frequency counter
  if(espnowTask.counter == 0)
  {
    espnowTask.startCounterTime = micros();
  }
  if(micros() - espnowTask.startCounterTime > 1000000)
  {
    espnowTask.frequency = espnowTask.counter;
    //Serial.println(espnowTask.counter);
    espnowTask.counter = 0;
  }

  //reTask frequency counter
  if(reTask.counter == 0)
  {
    reTask.startCounterTime = micros();
  }
  if(micros() - reTask.startCounterTime > 1000000)
  {
    reTask.frequency = reTask.counter;
    //Serial.println(reTask.counter);
    reTask.counter = 0;
  }

  //uartTask frequency counter
  if(uartTask.counter == 0)
  {
    uartTask.startCounterTime = micros();
  }
  if(micros() - uartTask.startCounterTime > 1000000)
  {
    uartTask.frequency = uartTask.counter;
    //Serial.println(uartTask.counter);
    uartTask.counter = 0;
  }

  //cirqueTask frequency counter
  if(sideModuleTask.counter == 0)
  {
    sideModuleTask.startCounterTime = micros();
  }
  if(micros() - sideModuleTask.startCounterTime > 1000000)
  {
    sideModuleTask.frequency = sideModuleTask.counter;
    //Serial.println(sideModuleTask.counter);
    sideModuleTask.counter = 0;
  }
  
  //cirqueTask frequency counter
  if(telemetryTask.counter == 0)
  {
    telemetryTask.startCounterTime = micros();
  }
  if(micros() - telemetryTask.startCounterTime > 1000000)
  {
    telemetryTask.frequency = telemetryTask.counter;
    //Serial.println(telemetryTask.counter);
    telemetryTask.counter = 0;
  }
}

/* Typical task outline

  //------------------------------------------------------Task
  if(micros() - Task.beginTime >= Task.interval)
  {
    Task.beginTime = micros();
    Task.inBetweenTime = Task.beginTime - Task.endTime;

    **functions

    Task.endTime = micros();
    Task.counter++;
    Task.duration = Task.endTime - Task.beginTime;

  }

  //Task frequency counter
  if(Task.counter == 0)
  {
    Task.startCounterTime = micros();
  }
  if(micros() - Task.startCounterTime > 1000000)
  {
    Task.frequency = Task.counter;
    debug.println(Task.counter);
    Task.counter = 0;
  }

*/

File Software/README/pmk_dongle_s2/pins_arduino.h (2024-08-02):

#ifndef Pins_Arduino_h
#define Pins_Arduino_h

#include <stdint.h>

// Default USB Settings
#define USB_VID 			0x046D
#define USB_PID 			0xC62B
#define USB_MANUFACTURER 	"PumaCorp"
#define USB_PRODUCT 		"PMK Dongle"
#define USB_SERIAL 			"0"


// Default USB FirmwareMSC Settings
#define USB_FW_MSC_VENDOR_ID 		"ESP32-S2" 		//max 8 chars
#define USB_FW_MSC_PRODUCT_ID 		"Firmware MSC"	//max 16 chars
#define USB_FW_MSC_PRODUCT_REVISION	"1.23" 			//max 4 chars
#define USB_FW_MSC_VOLUME_NAME 		"S2-Firmware" 	//max 11 chars
#define USB_FW_MSC_SERIAL_NUMBER 	0x00000000

static const uint8_t LED_BUILTIN = 15;
#define BUILTIN_LED  LED_BUILTIN // backward compatibility
#define LED_BUILTIN LED_BUILTIN  // allow testing #ifdef LED_BUILTIN

static const uint8_t TX = 39;
static const uint8_t RX = 37;

static const uint8_t SDA = 33;
static const uint8_t SCL = 35;

static const uint8_t SS    = 12;
static const uint8_t MOSI  = 11;
static const uint8_t MISO  = 9;
static const uint8_t SCK   = 7;

static const uint8_t A0 = 1;
static const uint8_t A1 = 2;
static const uint8_t A2 = 3;
static const uint8_t A3 = 4;
static const uint8_t A4 = 5;
static const uint8_t A5 = 6;
static const uint8_t A6 = 7;
static const uint8_t A7 = 8;
static const uint8_t A8 = 9;
static const uint8_t A9 = 10;
static const uint8_t A10 = 11;
static const uint8_t A11 = 12;
static const uint8_t A12 = 13;
static const uint8_t A13 = 14;
static const uint8_t A14 = 15;
static const uint8_t A15 = 16;
static const uint8_t A16 = 17;
static const uint8_t A17 = 18;
static const uint8_t A18 = 19;
static const uint8_t A19 = 20;

static const uint8_t T1 = 1;
static const uint8_t T2 = 2;
static const uint8_t T3 = 3;
static const uint8_t T4 = 4;
static const uint8_t T5 = 5;
static const uint8_t T6 = 6;
static const uint8_t T7 = 7;
static const uint8_t T8 = 8;
static const uint8_t T9 = 9;
static const uint8_t T10 = 10;
static const uint8_t T11 = 11;
static const uint8_t T12 = 12;
static const uint8_t T13 = 13;
static const uint8_t T14 = 14;

static const uint8_t DAC1 = 17;
static const uint8_t DAC2 = 18;

#endif /* Pins_Arduino_h */

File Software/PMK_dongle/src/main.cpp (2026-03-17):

#include <Arduino.h>
#include <string>
#include <cstring>
#include <cstdint>

//TO DO delete this file
#include "config.h"

#define FIRMWARE_REV "dongle-dev-1.1.0dev"

//Include library
#include "WiFi.h"
#include "esp_now.h"
#include "esp_wifi.h"
#include "SPI.h"
#include "SdFat.h"
#include "Adafruit_SPIFlash.h"
#include "Adafruit_TinyUSB.h"
#include "SimpleCLI.h"

//Include files
#include "variables.h"

#include "pmk.h"
#include "USBHandle.h"
#include "espNowHandle.h"
#include "fsHandle.h"
#include "MSCHandle.h"
#include "commandHandle.h"



void loopCount(); //For function telemetry purpose / Homemade Ultra lite RTOS



//===========================================
//===========================================
//====================Setup==================
//===========================================
//===========================================
void setup()
{

  Serial.begin(115200);

  //===========================================
  //====================CLI====================
  //===========================================
  cliSetup();



  //===========================================
  //====================FatFS==================
  //===========================================
  //Initiate flash
  if(!flash.begin())
  {
    Serial.printf("An Error has occurred while mounting FatFS\r\n");
    return;
  }
  else
  {
    Serial.printf("File system is ok\r\n");
  }
  
  // Set disk vendor id, product id and revision with string up to 8, 16, 4 characters respectively
  usb_msc.setID("PMK", "Config Flash", "0.1");

  // Set read callback
  usb_msc.setReadWriteCallback(msc_read_cba, msc_write_cba, msc_flush_cba);

  // Set disk size, block size should be 512 regardless of spi flash page size
  usb_msc.setCapacity(flash.size()/512, 512);

  // MSC is ready for read/write
  usb_msc.setReadyCallback(0, msc_ready_callbacka);

  usb_msc.begin();

  // Init file system on the flash, format if not formatted
  while(!fatfs.begin(&flash))
  {
    Serial.printf("Failed to init files system, flash may not be formatted\r\n");
    Serial.printf("Formatting the flash for FatFS use...\r\n");
    format_fat12();
    check_fat12();
    Serial.printf("Flash formatted successfully\r\n");
    ESP.restart();
  }

  pinMode(LED_DATA_PIN, OUTPUT);
  digitalWrite(LED_DATA_PIN, 1);

  Serial.printf("Dongle is booting\r\n");
  Serial.printf("Firmware rev: %s\r\n", FIRMWARE_REV);
  Serial.printf("Firmware was built the: %s at %s\r\n\r\n", __DATE__, __TIME__);

  Serial.printf("__          __  _                            _          _____  __  __ _  __ \r\n");
  Serial.printf("\\ \\        / / | |                          | |        |  __ \\|  \\/  | |/ / \r\n");
  Serial.printf(" \\ \\  /\\  / /__| | ___ ___  _ __ ___   ___  | |_ ___   | |__) | \\  / | ' /  \r\n");
  Serial.printf("  \\ \\/  \\/ / _ \\ |/ __/ _ \\| '_ ` _ \\ / _ \\ | __/ _ \\  |  ___/| |\\/| |  <   \r\n");
  Serial.printf("   \\  /\\  /  __/ | (_| (_) | | | | | |  __/ | || (_) | | |    | |  | | . \\  \r\n");
  Serial.printf("    \\/  \\/ \\___|_|\\___\\___/|_| |_| |_|\\___| \\__ \\___/  |_|    |_|  |_|_|\\_\\ \r\n\r\n\r\n");



  //===========================================
  //====================USB====================
  //===========================================
  // Set up HID
  //usb_hid.setBootProtocol(HID_ITF_PROTOCOL_KEYBOARD);
  usb_hid.setPollInterval(2);
  usb_hid.setReportDescriptor(desc_hid_report, sizeof(desc_hid_report));
  usb_hid.setStringDescriptor("PMK");

  // Set up output report (on control endpoint) for Capslock indicator
  usb_hid.setReportCallback(NULL, hid_report_callback);
  
  usb_hid.begin();

  // Set up midi
  usbMIDI.begin();


  //Serial.printf("Waiting for USB HID to be mounted...\r\n");
  while( !TinyUSBDevice.mounted() ) delay(1);

  //====================================================
  //====================Wifi/ESP Now====================
  //====================================================
  Serial.printf("Starting WiFi\r\n");
  WiFi.mode(WIFI_STA);
  WiFi.setTxPower(WIFI_POWER_19dBm);
  Serial.printf("New WiFi power: ");
  Serial.println(WiFi.getTxPower());
  Serial.print("Dongle MAC address: " + WiFi.macAddress() + "\r\n");

  if(esp_now_init() != ESP_OK) 
  {
    Serial.printf("Error initializing ESP-NOW\r\n");
    return;
  }
  else
  {
    Serial.printf("Succesfully initiated ESP-NOW\r\n\r\n");
  }

  esp_now_register_send_cb(OnEspNowDataSent);
  //esp_wifi_config_espnow_rate(WIFI_IF_STA, WIFI_PHY_RATE_54M);

  //Register peer
  peerInfo.ifidx = WIFI_IF_STA;
  peerInfo.channel = 3;  
  peerInfo.encrypt = false;



  //===========================================
  //====================Config=================
  //===========================================

  loadConfiguration();

  //configDeej();

  setupPMK();

  esp_now_register_recv_cb(OnEspNowDataRecv);

}
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

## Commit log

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2022-11-15 trying littlefs
    [partitions.csv]
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2022-12-20 yeah, schematic started
    [PMK_Keyboard.kicad_pcb, PMK_Keyboard.kicad_sch]
2022-12-20 project update
    [PMK_Keyboard.kicad_pcb, PMK_Keyboard.kicad_sch]
2022-12-20 Initiated layout
    [PMK_Keyboard.kicad_pcb, PMK_Keyboard.kicad_sch]
2022-12-20 Added some sort of layout
    [PMK_Keyboard.kicad_pcb]
2022-12-21 trying some layout scale
    [PMK_Keyboard.kicad_pcb, pmk-v1.dxf]
2022-12-22 updated layout
    [PMK_Keyboard.kicad_pcb]
2023-01-03 finally the correct pcb dimension
    [PMK_Keyboard.STL, PMK_Keyboard.step]
2023-01-04 with FN row
    [PMK_Keyboard.kicad_pcb]
2023-01-05 no function row
    [PMK_Keyboard.kicad_pcb]
2023-01-05 updated outline
    [PMK_Keyboard.kicad_pcb]
2023-01-05 changed switch footprint
    [PMK_Keyboard.kicad_pcb, PMK_Keyboard.kicad_sch]
2023-01-05 quick routing test
    [PMK_Keyboard.kicad_pcb]
2023-01-06 Started routing
    [PMK_Keyboard.kicad_pcb, PMK_Keyboard.kicad_sch]
2023-01-06 Routing in progress
    [PMK_Keyboard.kicad_pcb]
2023-01-08 quick routing update
    [PMK_Keyboard.kicad_pcb]
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2023-01-12 yay routing to switches is done
    [PMK_Keyboard.kicad_pcb]
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2023-01-19 Added ESP32 to schematic
    [PMK_Dongle.kicad_sch, PMK_Keyboard.kicad_sch]
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2023-01-22 Layout is almost done
    [PMK_Dongle.kicad_pcb, PMK_Dongle.kicad_sch]
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2023-01-24 Updated routing to jlc specifications
    [PMK_Dongle.kicad_pcb]
2023-01-24 Routing is almost done, just need to check quartz
    [PMK_Dongle.kicad_pcb, PMK_Dongle.kicad_sch]
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2023-01-25 Dongle routing is done
    [PMK_Dongle.kicad_pcb, PMK_Dongle.kicad_sch]
2023-01-30 Redone routing for 180mm version
    [PMK_Keyboard.kicad_pcb, PMK_Keyboard.kicad_sch]
2023-01-31 Started routing the pullups
    [PMK_Keyboard.kicad_pcb, PMK_Keyboard.kicad_sch]
2023-01-31 Keyboard routing is ongoing
    [PMK_Keyboard.kicad_pcb, PMK_Keyboard.kicad_sch]
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2023-02-03 Worked on hierachic page again
    [1S_Charger.kicad_sch, 300-Power.kicad_sch, Connectors.kicad_sch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]
2023-02-06 Worked on hierachic sheet
    [Connectors.kicad_sch, ESP32S2FH4S2.kicad_sch, PMK_Keyboard.kicad_sch]
2023-02-06 Again on hierachic sheet
    [1S_Charger.kicad_sch, Connectors.kicad_sch, ESP32S2FH4S2.kicad_sch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]
2023-02-07 Schematic is done, only possible update is change of ESP pins
    [1S_Charger.kicad_sch, Connectors.kicad_sch, ESP32S2FH4S2.kicad_sch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]
2023-02-07 Routing is finally updated
    [1S_Charger.kicad_sch, Connectors.kicad_sch, ESP32S2FH4S2.kicad_sch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]
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2023-02-08 Added the correct ref for USB C connector
    [300-Power.kicad_sch, Connectors.kicad_sch, ESP32S2FH4S2.kicad_sch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]
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2023-02-20 Routing is almost done
    [1S_Charger.kicad_sch, Connectors.kicad_sch, ESP32S2FH4S2.kicad_sch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]
2023-02-20 added schematic for reverse polarity protection
2023-02-27 Added reverse polarity battery management
    [Connectors.kicad_sch]
2023-03-02 removed anti reverse polarity system
    [Connectors.kicad_sch]
2023-03-02 Routed the debug uart
    [PMK_Keyboard.kicad_pcb]
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2023-03-13 HW00 of keyboard is done but ugly
    [PMK_Dongle.kicad_pcb, PMK_Keyboard.kicad_pcb, bom.csv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]
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2023-04-29 made a first version of the dongle casing
    [Casing.SLDPRT, Casing.STL, Dongle assembly.SLDASM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]
2023-04-30 Made a 2nd version of casing
    [Casing2.2mm.STL, Dongle assembly.SLDASM]
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2023-05-14 Working on the keyboard part
    [holder^keycap holder.STL, keycap holder.SLDASM, keycap matrice.SLDPRT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]
2023-05-16 mmh I broke pulsar
    [ledHandle.h, main.cpp, variables.h]
2023-05-18 fixing some of the compiling errors
    [ledHandle.h, main.cpp]
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2023-05-31 added step file of key layout
    [PMK_Keyboard.DXF, PMK_Keyboard.SLDASM, PMK_Keyboard.SLDDRW]
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2023-09-08 FirmwareMSC added, "fixed latency"
    [main.cpp]
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2023-10-02 started 3D mouse CAD
    [top.SLDPRT]
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2023-12-10 added mecha for deej
    [18650.SLDPRT, Bottom.SLDPRT, Bottom.STL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]
2023-12-27 moved dongle pcb to HW00
    [PMK_Dongle.kicad_pcb, PMK_Dongle.kicad_sch, bom.csv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]
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2024-02-12 Need to route Shift registers
    [PMK_Keyboard_HW01.kicad_pcb, PSoM.kicad_sch]
2024-02-13 Routing still going on
    [ShiftRegisterSwitch.kicad_sch]
2024-02-13 a bit of routing
    [Connectors.kicad_sch, ShiftRegisterSwitch.kicad_sch]
2024-02-14 Need to add some silkscreenthen done!
    [Connectors.kicad_sch, PMK_Keyboard_HW01.kicad_sch, PSoM.kicad_sch]
2024-02-14 commit before trying kicad 8.0 rc2
    [bom.csv, designators.csv, positions.csv]
2024-02-15 added mounting holes + fix in ref des
    [Battery.SLDPRT, Connectors.kicad_sch, LEDs.kicad_sch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]
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2024-03-15 quick fix for previous commit
    [main.cpp, variables.h]
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2024-04-03 fixed reading button 0 bug
    [main.cpp, variables.h]
2024-04-04 Fixed led number, added rotary encoder pins
    [main.cpp, variables.h]
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2024-04-09 Rotary encoder reading added
    Still need HW fix to had capa ton rotary encoder...
    [main.cpp, variables.h]
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2024-04-10 small cleanup + export case stl
    [UpperCasing.STL]
2024-04-17 updated mouse code + small fix
    [PMK_economis.xlsx]
2024-04-22 added keyboard knob + quick dongle cleanup
    [RotaryKnob.SLDPRT, RotaryKnob.STL]
2024-04-22 consider rotary encoder fix done...
    [main.cpp]
2024-04-22 updated knurling on knob
    [RotaryKnob.SLDPRT, RotaryKnob.STL]
2024-04-22 updated tolerance
    [RotaryKnob.SLDPRT, RotaryKnob.STL]
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2024-05-04 fixed a few uart commands
    [main.cpp]
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2024-06-08 working on schematic 02
    [Connectors.kicad_sch, LEDs.kicad_sch, PMK_Keyboard_02.kicad_pro.kicad_sch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]
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2024-06-12 updated key switch to kailh v2
    [Connectors.kicad_sch, LEDs.kicad_sch, PMK_Keyboard_02.kicad_pro.kicad_pcb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]
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2024-06-16 added production files for spacemouse_00
    [PMK_SpaceMouse_00.kicad_pcb, bom.csv, designators.csv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]
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2024-06-26 fixed typo on silkscreen, no new rev for this fix
    [PMK_Keyboard_02.kicad_pro.kicad_pcb]
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2024-07-15 added right top plate stl
    [Plate.SLDPRT, right plate TO BE MIRRORED.STL]
2024-07-23 fixed spi settings
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2024-07-30 moved right plate location
    [right plate TO BE MIRRORED.STL]
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2024-08-06 it aint clean but it does work! fixed format
    [diskio.h]
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2024-08-16 added spacemouse_01
    fixed the 2 unrouted paths
    [PMK_SpaceMouse_01.kicad_pcb, PMK_SpaceMouse_01.kicad_sch, bom.csv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]
2024-08-16 Routing PMK_Dongle_S2_HW01
    fixed the previous issues + shortened by 3mm
    [PMK_Dongle_HW01.kicad_pcb, PMK_Dongle_HW01.kicad_sch, bom.csv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]
2024-08-18 working on PMK-dongle_S3 schematic
    [PMK_Dongle_HW01.kicad_sch, PMK_Dongle_S3_HW00.kicad_pcb, PMK_Dongle_S3_HW00.kicad_sch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]
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2024-09-05 made a bigger psom hole
    [Foam.SLDPRT, Plate.SLDPRT]
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2024-09-28 Trying to reduce input lag + fixed force layer bug
    [main.cpp, variables.h]
2024-10-17 added mouse shell prototype
    [Shell.SLDPRT]
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2024-10-23 have i just resolved the input lag issue?
    [ioHandle.h, variables.h]
2024-10-25 updated refresh rate to 200Hz for debounce fix
    [variables.h]
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2024-11-28 Create 3D mouse knob.FCStd
    [3D mouse knob.FCStd]
2024-11-30 finalised 3D mouse knob
    [3D mouse knob-BodyPolarPattern001.stl, 3D mouse knob.FCStd]
2025-06-24 fixed layout and keyboard debug
    and added command for setting channel
    [main.cpp]
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2025-06-30 fixed hole size for order
    [PMK_Dongle_HW01.kicad_pcb]
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
